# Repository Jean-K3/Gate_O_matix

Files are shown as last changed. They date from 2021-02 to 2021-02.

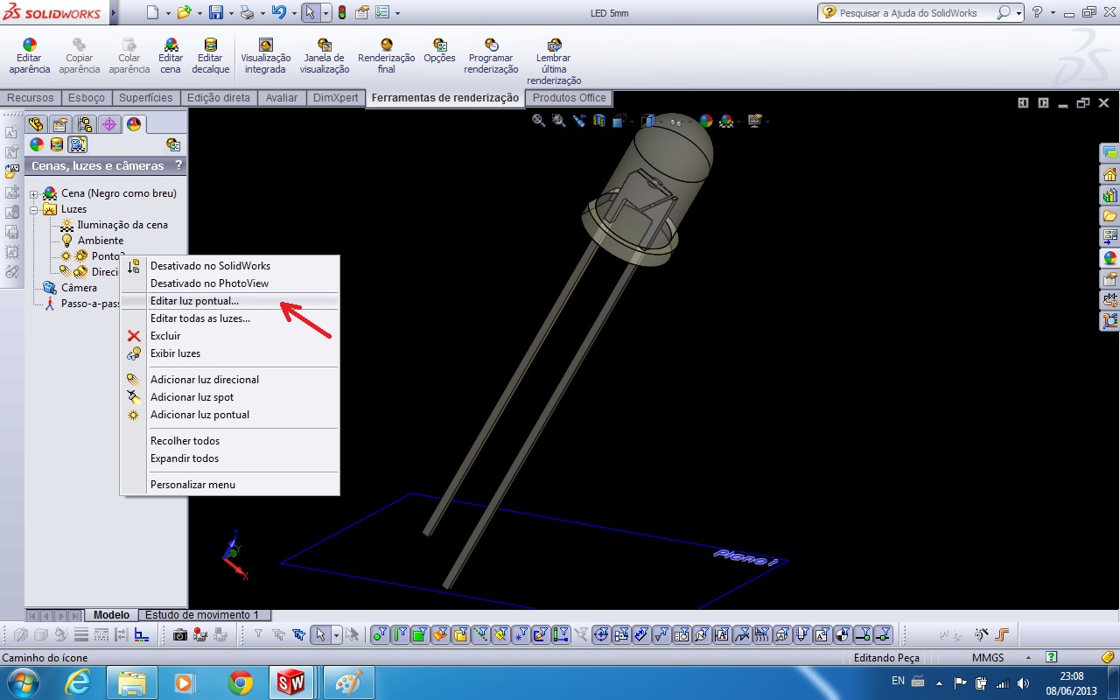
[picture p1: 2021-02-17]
Kicad/My_library/Mes_modèles_3D/LED_5mm/LED 9.jpg

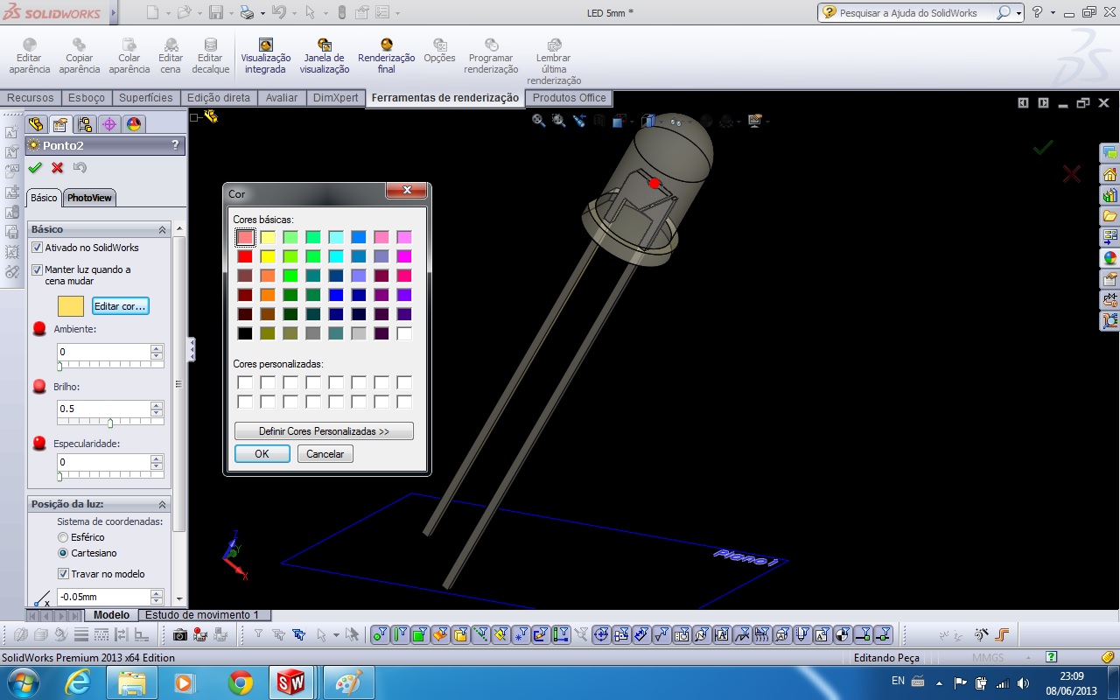
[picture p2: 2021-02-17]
Kicad/My_library/Mes_modèles_3D/LED_5mm/LED 10.jpg

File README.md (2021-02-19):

  Gate sequencer by Plop

  Update 17 FEB 2021

  64 step sequencer, 8 parts, multiple play mode, eurorack format.

  ________________________________________________________________________________________________
  ________________________________________________________________________________________________
  ________________________________________________________________________________________________

  TODO :

    SOFTWARE

      -Clock multiplier/divider per part
      -Detect clock internal/external (switching jack)
      -Reset -> interupt
      -Patern choice
      -Save/Load (SD card)

    HARDWARE

      -Use faster microcontroler (blue pills or teensy ?)
      -Add switching jack for clock
      -Add SD card
      -12v alimentation
      -"transistorisation" des entrées/sorties

    SCHEMATIC & PCB
    
      -Resistor value for LED & screen
      -Routing Main_Board
      -Drawing CPU_Board

  DONE :

    -Tempo
    -Screen driver
    -LED driver
    -Key matrix
    -Part choice
    -Number of step
    -Pages navigation
    -Step ON-OFF
    -Play mode
    -Fill/Clear
    -Copy/Past
    -Pause/Play/Stop
    -Gate size
    -Step jump
    -Reset
    -Internal clock

  ________________________________________________________________________________________________
  ________________________________________________________________________________________________
  ________________________________________________________________________________________________

  FUNCTIONS :

    Buttons =
        -Step on/off
        -Shift + step button = step jump
        -Fill
        -Fill + shift = Clear
        -Copy/Paste
        -Copy/Paste + shift = Save
        -Pause/Play
        -Pause/Play + shift = Stop

    Encoders =
        -Tempo
        -Tempo + push = clock divider
        -Gate length
        -Gate length + push = Number of step
        -Page navigation
        -Page navigation + push = Play mode

    Selector =
        -Part choice

    Play mode =
        -Forward
        -Backward
        -Ping Pong
        -Random
        -Brownien

  --------------------------------------------------------------------------

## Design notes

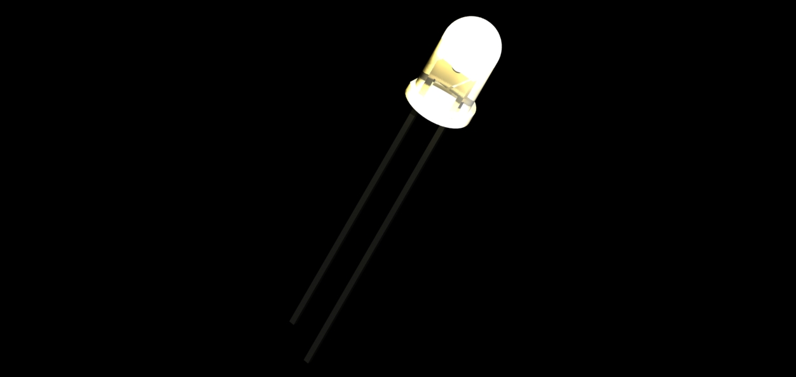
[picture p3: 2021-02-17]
Kicad/My_library/Mes_modèles_3D/LED_5mm/LED 1.JPG

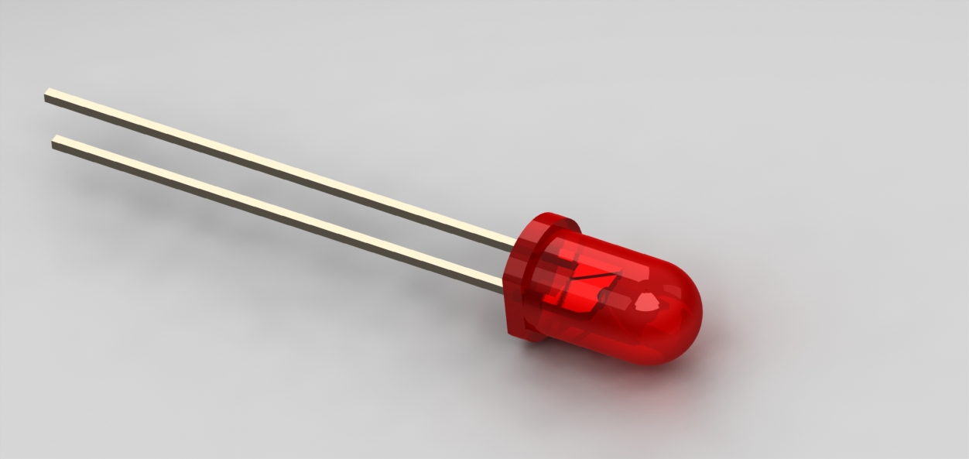
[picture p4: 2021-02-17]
Kicad/My_library/Mes_modèles_3D/LED_5mm/Renderings/LED 13.JPG

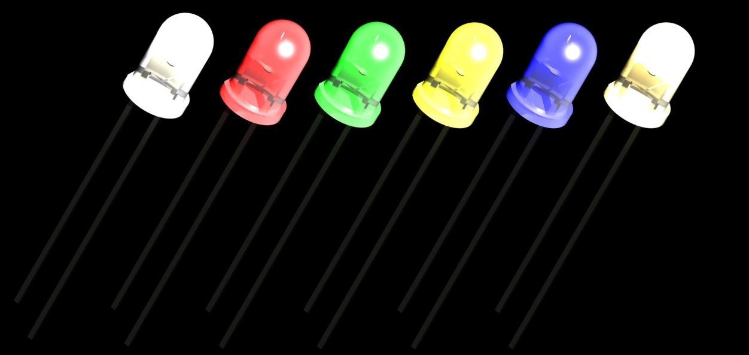
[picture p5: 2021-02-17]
Kicad/My_library/Mes_modèles_3D/LED_5mm/LED 7.jpg

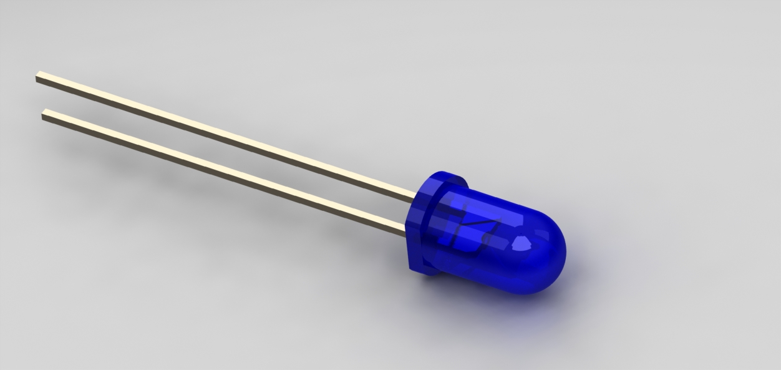
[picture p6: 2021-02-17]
Kicad/My_library/Mes_modèles_3D/LED_5mm/Renderings/LED 17.JPG

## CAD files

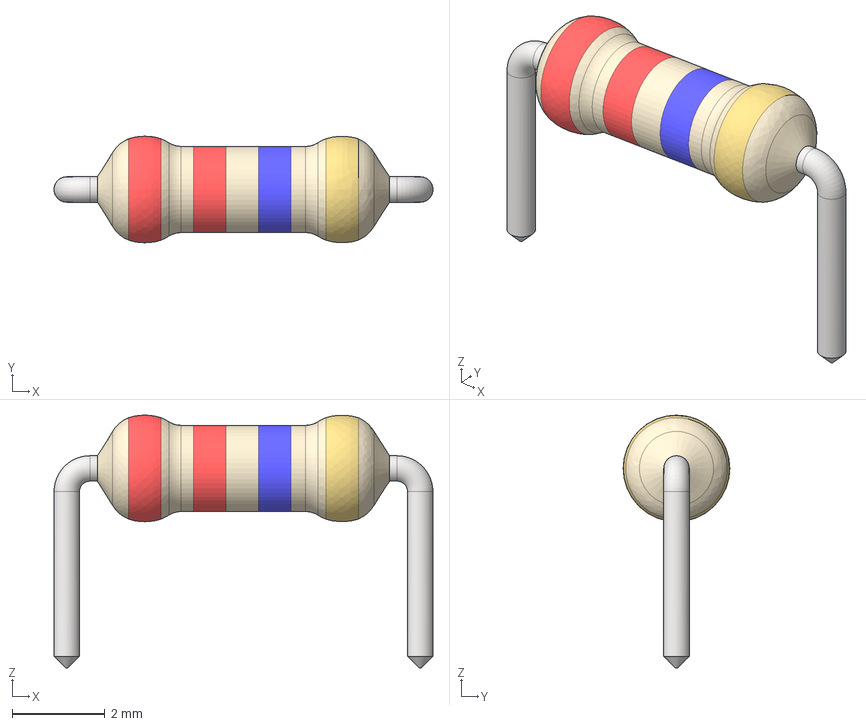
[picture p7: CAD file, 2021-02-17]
Kicad/My_library/Mes_modèles_3D/216-resistors-in-tht-series-e24-from-1ohm-to-910mohm-1.snapshot.3/Yageo CFR-25 Resistor Axial P7.62mm 22,0 MOhm.stp
8.17 x 2.30 x 5.45 mm

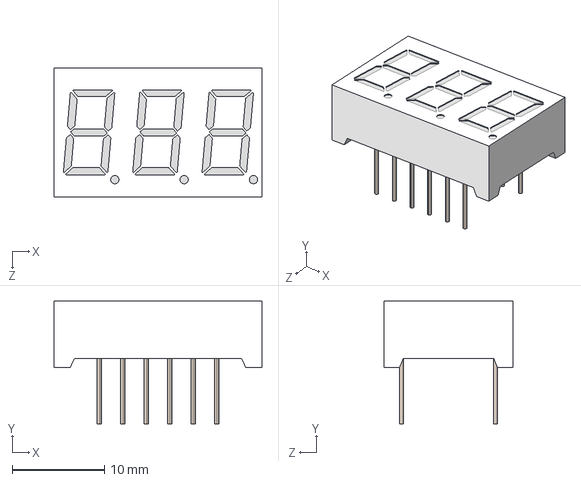
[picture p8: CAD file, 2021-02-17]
Kicad/My_library/Mes_modèles_3D/7 Segment Display/SD-3361_X.STEP
22.5 x 13.3 x 14.0 mm

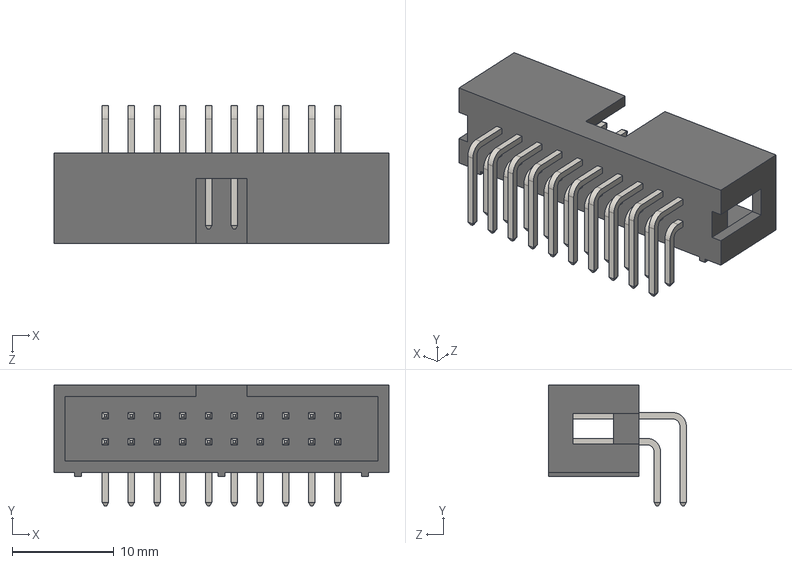
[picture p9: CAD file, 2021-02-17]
Kicad/My_library/Mes_modèles_3D/bh-connector-set-1.snapshot.1/BH-20R.STEP
33.0 x 11.9 x 13.6 mm

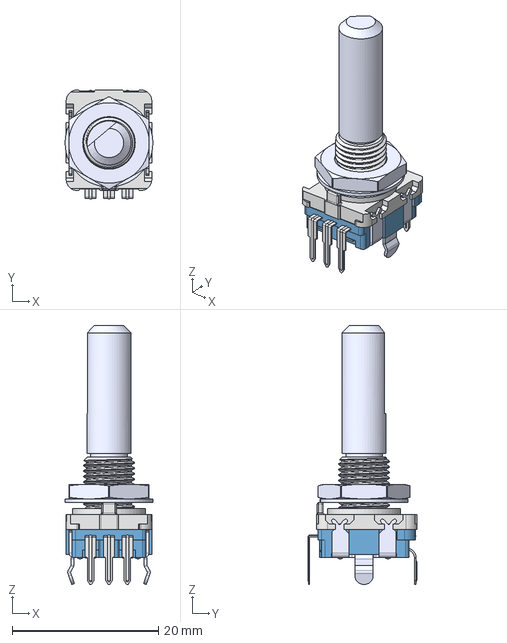
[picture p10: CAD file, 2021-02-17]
Kicad/My_library/Mes_modèles_3D/Encoders/EC11B-SW-Vert-25F-blue.step
12.0 x 14.9 x 35.4 mm

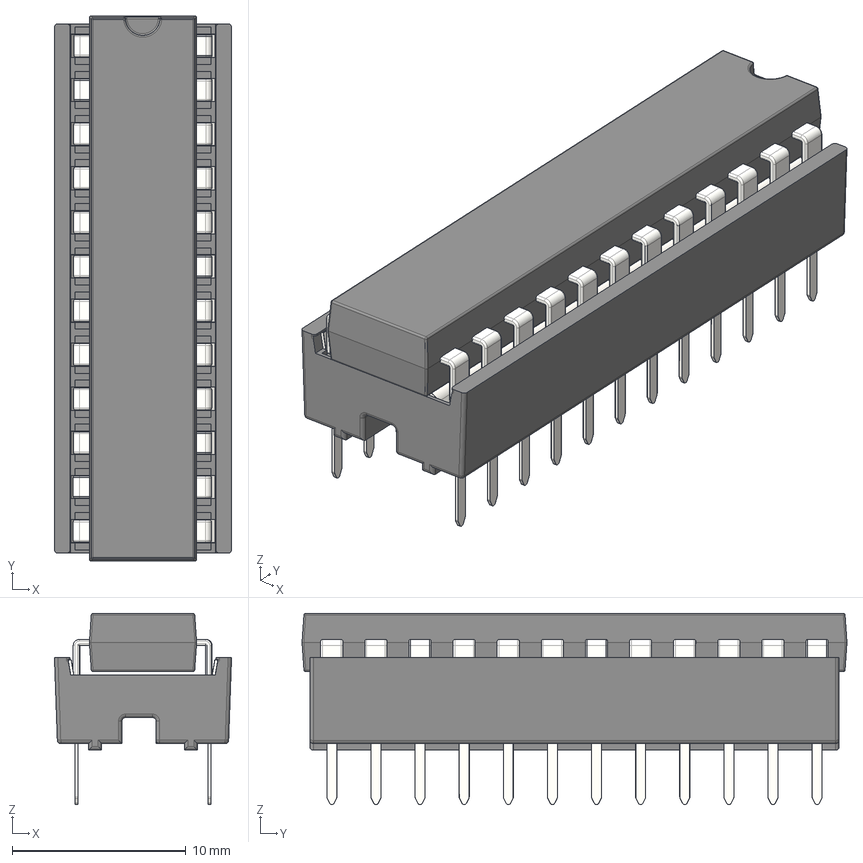
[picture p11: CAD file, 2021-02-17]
Kicad/My_library/Mes_modèles_3D/IC_Sockets/DIP-24 W7.62mm IC with Socket.stp
10.2 x 31.4 x 11.0 mm
Stamped Dual Wipe Contact for DIP Sockets x 24
Body DIP-24 P7.62mm Socket
IC Beinchen x 24
DIP-24 W7.62

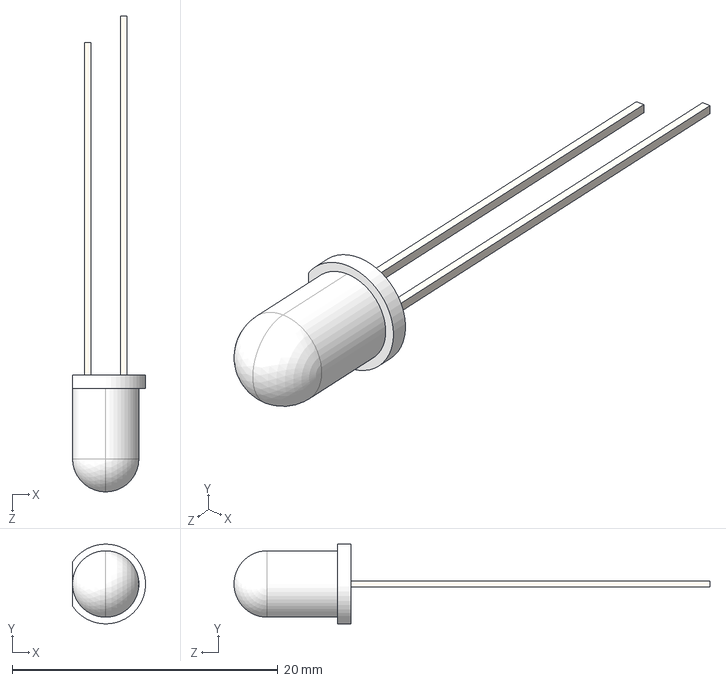
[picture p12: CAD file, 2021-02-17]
Kicad/My_library/Mes_modèles_3D/LED_5mm/LED 5mm.STEP
5.49 x 6.00 x 35.8 mm

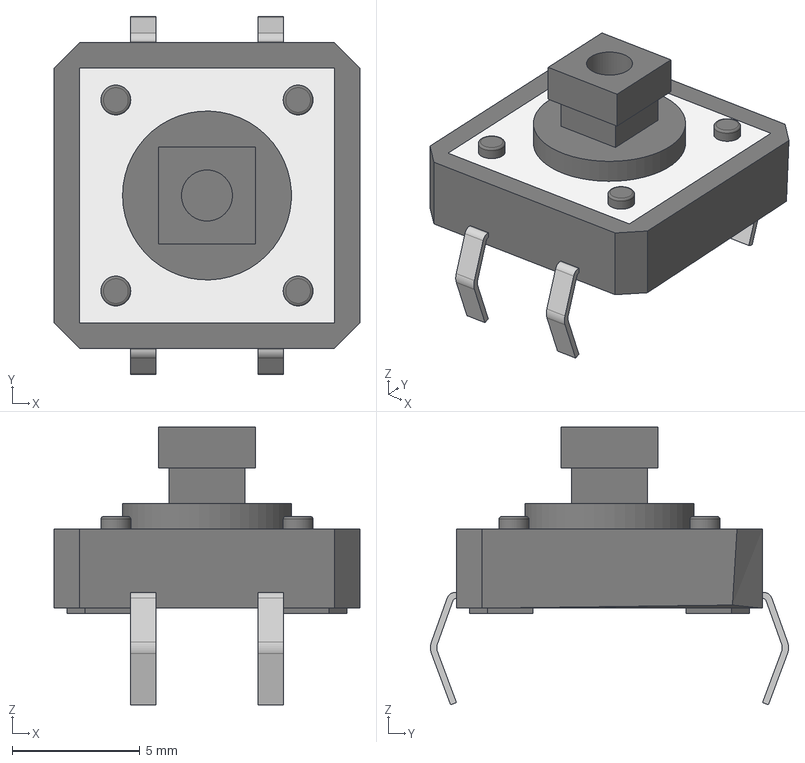
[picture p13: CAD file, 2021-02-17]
Kicad/My_library/Mes_modèles_3D/Switch/TactSwitch.stp
12.0 x 14.0 x 10.9 mm

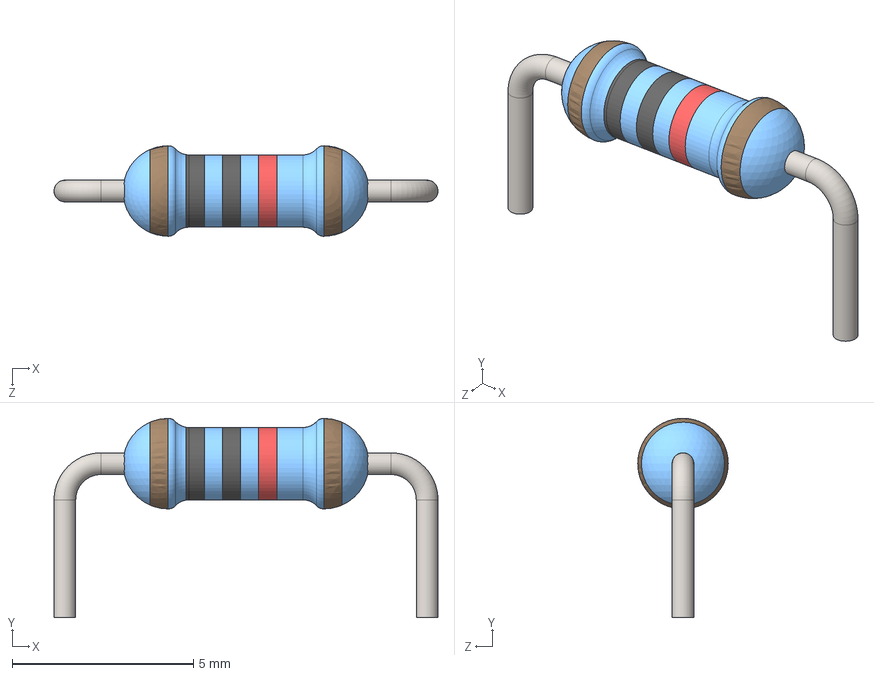
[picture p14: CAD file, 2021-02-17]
Kicad/My_library/Mes_modèles_3D/tht-resistor-1.snapshot.11/10K-1%.STEP
10.6 x 5.50 x 2.50 mm
PinH0.6_10^10K-1%
Body^10K-1%
ColourBand_1^10K-1%
ColourBand_2^10K-1%
ColourBand_3^10K-1%
ColourBand_4^10K-1%
ColourBand_5^10K-1%

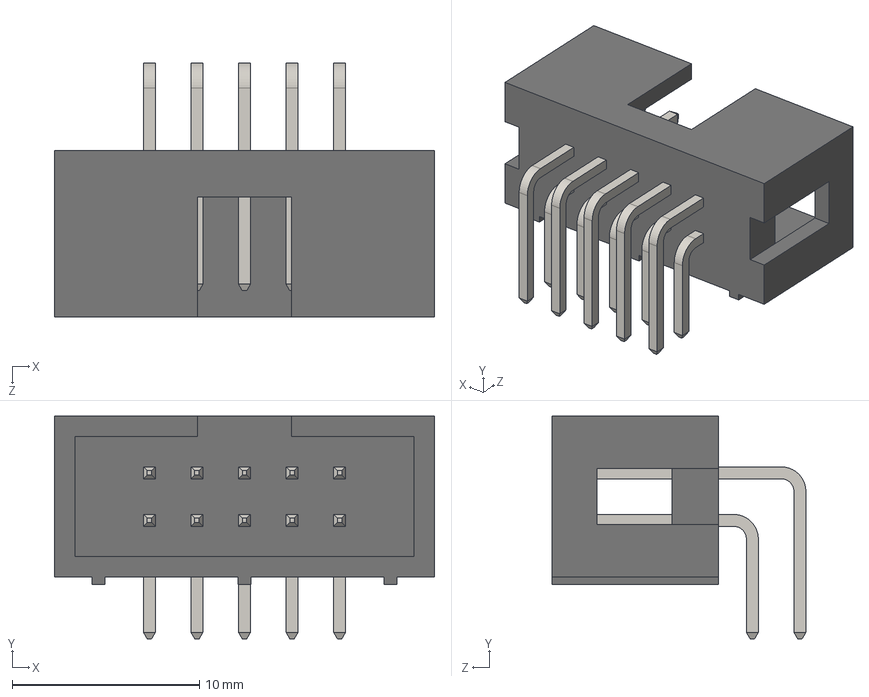
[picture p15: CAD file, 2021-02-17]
Kicad/My_library/Mes_modèles_3D/bh-connector-set-1.snapshot.1/BH-10R.STEP
20.3 x 11.9 x 13.6 mm

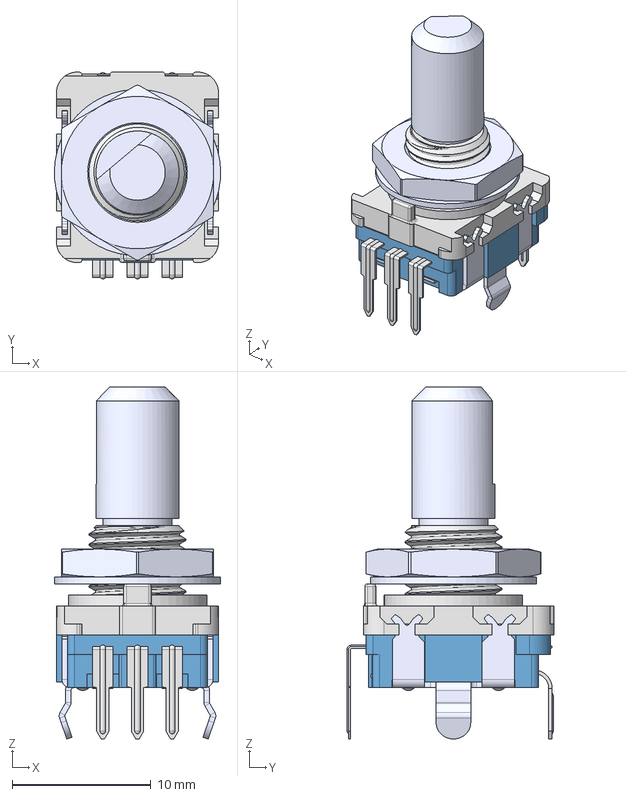
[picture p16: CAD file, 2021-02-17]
Kicad/My_library/Mes_modèles_3D/Encoders/EC11B-SW-Vert-15F-blue.step
12.0 x 14.9 x 25.4 mm

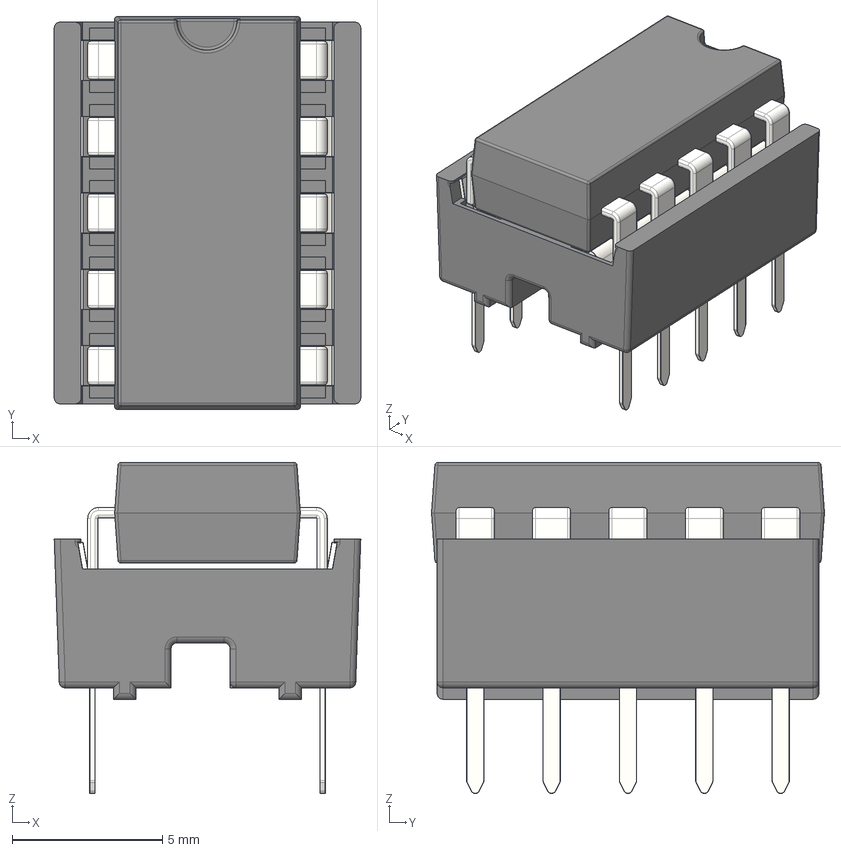
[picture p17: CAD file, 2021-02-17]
Kicad/My_library/Mes_modèles_3D/IC_Sockets/DIP-10 W7.62mm IC with Socket.stp
10.2 x 13.1 x 11.0 mm
Stamped Dual Wipe Contact for DIP Sockets x 10
Body DIP-10 P7.62mm Socket
IC Beinchen x 10
DIP-10 W7.62

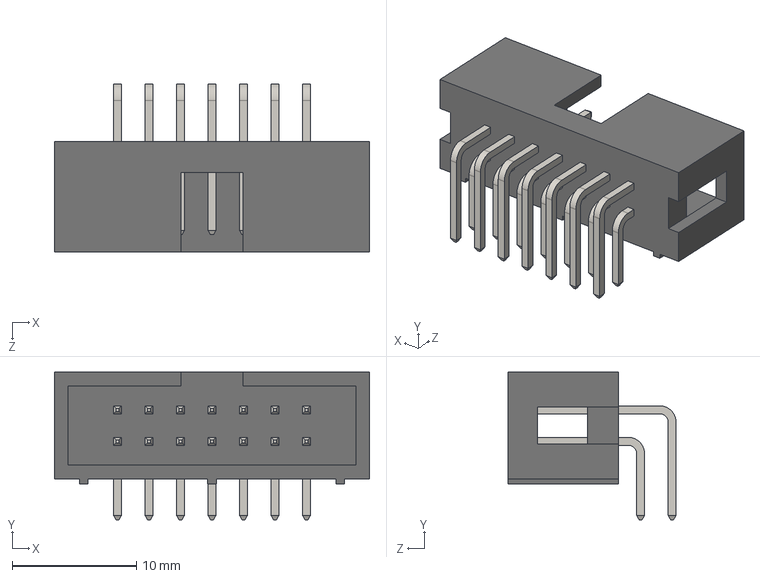
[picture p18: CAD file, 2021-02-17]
Kicad/My_library/Mes_modèles_3D/bh-connector-set-1.snapshot.1/BH-14R.STEP
25.4 x 11.9 x 13.6 mm

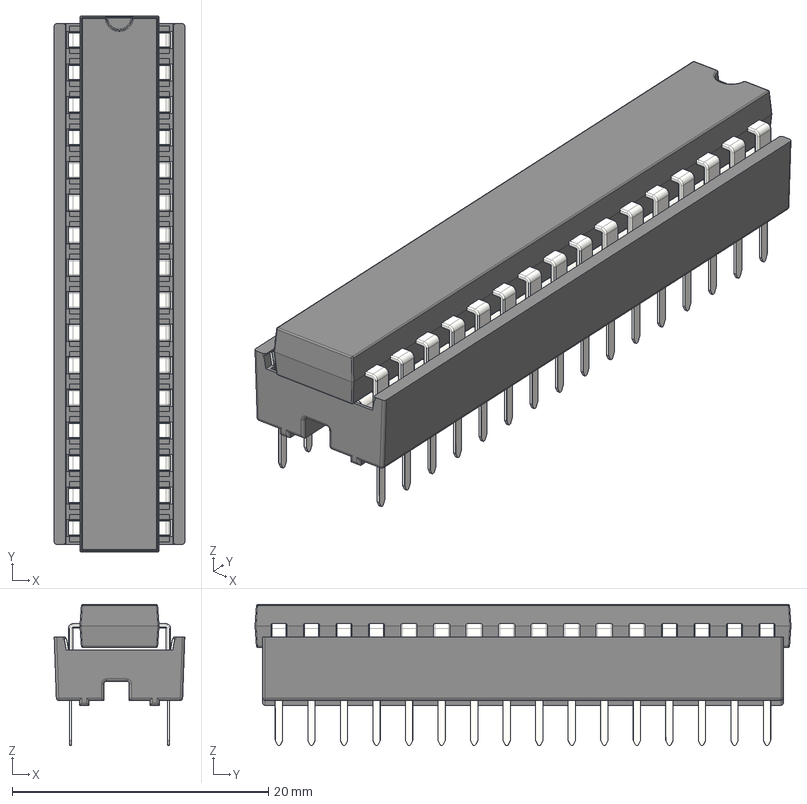
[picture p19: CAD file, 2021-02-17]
Kicad/My_library/Mes_modèles_3D/IC_Sockets/DIP-32 W7.62mm IC with Socket.stp
10.2 x 41.8 x 11.0 mm
Stamped Dual Wipe Contact for DIP Sockets x 32
Body DIP-48 Socket
IC Beinchen x 32
DIP-32 W7.62

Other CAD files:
Kicad/My_library/Mes_modèles_3D/216-resistors-in-tht-series-e24-from-1ohm-to-910mohm-1.snapshot.3/Yageo CFR-25 Resistor Axial P7.62mm 11,0 kOhm.stp
Kicad/My_library/Mes_modèles_3D/tht-resistor-1.snapshot.11/33K-1%.STEP
Kicad/My_library/Mes_modèles_3D/216-resistors-in-tht-series-e24-from-1ohm-to-910mohm-1.snapshot.3/Yageo CFR-25 Resistor Axial P7.62mm 1,3 Ohm.stp
Kicad/My_library/Mes_modèles_3D/Encoders/EC11B-SW-Vert-25R-black.step
Kicad/My_library/Mes_modèles_3D/tht-resistor-1.snapshot.11/560R-1%.STEP
Kicad/My_library/Mes_modèles_3D/216-resistors-in-tht-series-e24-from-1ohm-to-910mohm-1.snapshot.3/Yageo CFR-25 Resistor Axial P7.62mm 1,0 MOhm.stp
Kicad/My_library/Mes_modèles_3D/216-resistors-in-tht-series-e24-from-1ohm-to-910mohm-1.snapshot.3/Yageo CFR-25 Resistor Axial P7.62mm 1,0 Ohm.stp
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

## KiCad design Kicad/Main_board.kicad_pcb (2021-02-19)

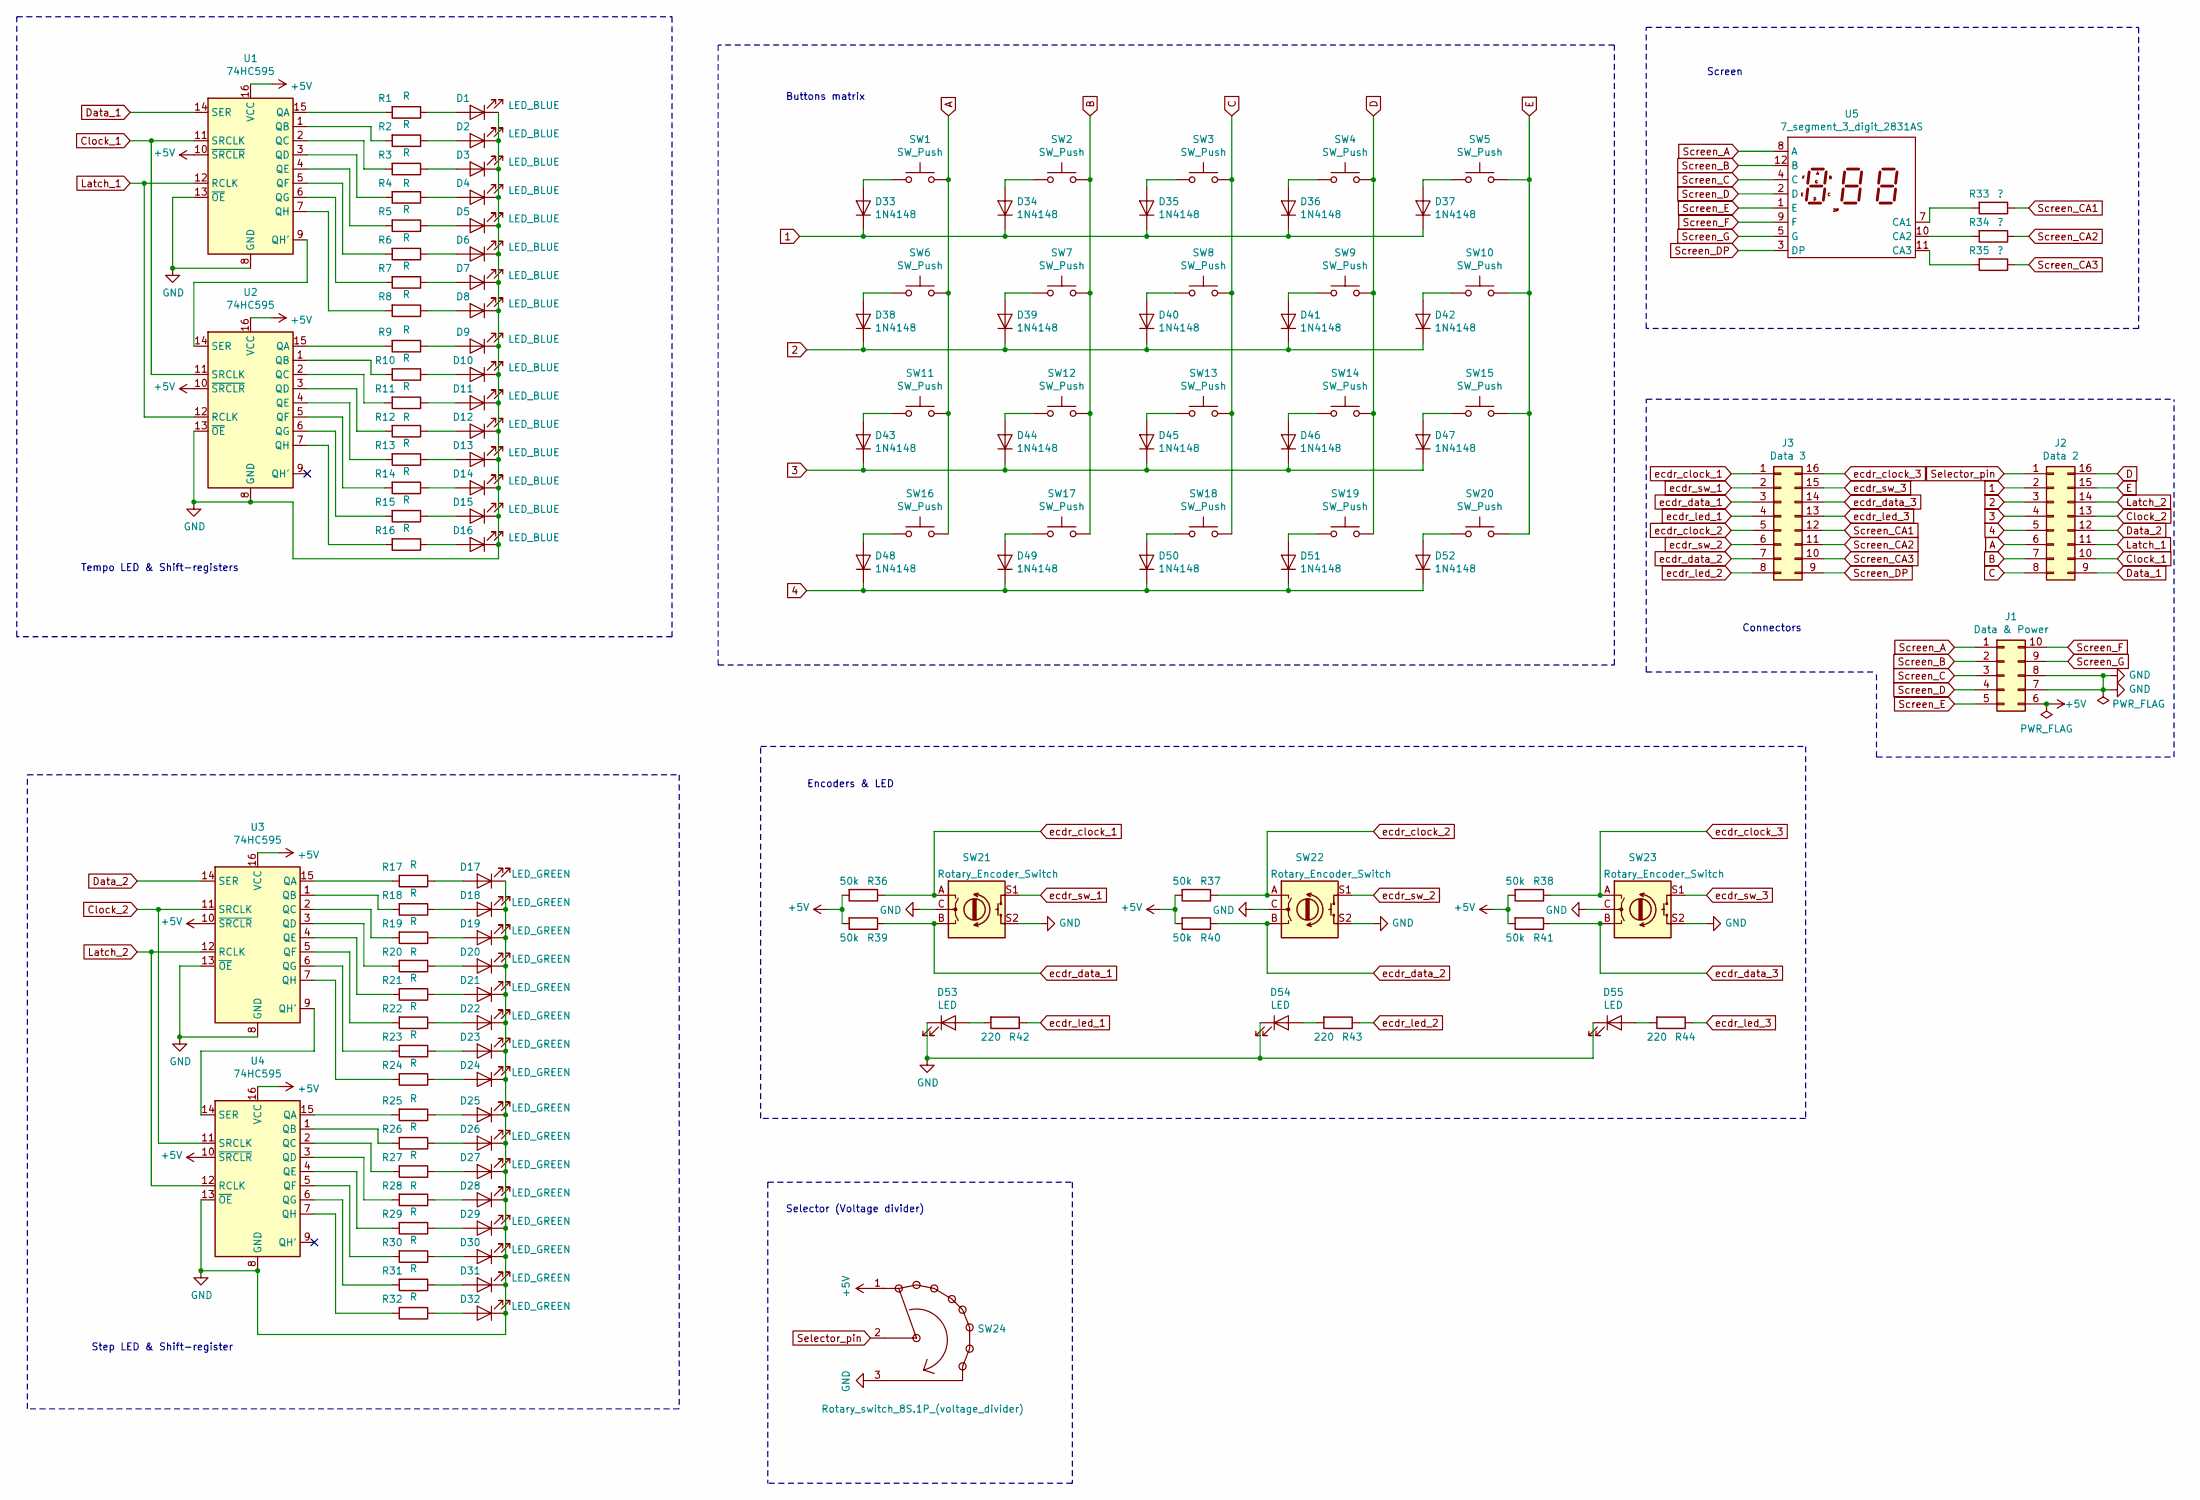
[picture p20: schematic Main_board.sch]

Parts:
D1, D2, D3, D4, D5, D6, D7, D8, D9, D10, D11, D12, D13, D14, D15, D16: LED_BLUE; LED_5.0mm
D17, D18, D19, D20, D21, D22, D23, D24, D25, D26, D27, D28, D29, D30, D31, D32: LED_GREEN; LED_5.0mm
D33, D34, D35, D36, D37, D38, D39, D40, D41, D42, D43, D44, D45, D46, D47, D48, D49, D50, D51, D52: 1N4148; D_DO-35_SOD27_P7.62mm_Horizontal
D53, D54, D55: LED; LED_5.0mm
J1: Data & Power; IDC-Header_2x05
J2: Data 2; IDC-Header_2x08
J3: Data 3; IDC-Header_2x08
R1, R2, R3, R4, R5, R6, R7, R8, R9, R10, R11, R12, R13, R14, R15, R16, R17, R18, R19, R20, R21, R22, R23, R24, R25, R26, R27, R28, R29, R30, R31, R32: R; Resistance
R33, R34, R35: ?; Resistance
R36, R37, R38, R39, R40, R41: 50k; Resistance
R42, R43, R44: 220; Resistance
SW1, SW2, SW3, SW4, SW5, SW6, SW7, SW8, SW9, SW10, SW11, SW12, SW13, SW14, SW15, SW16, SW17, SW18, SW19, SW20: SW_Push; SW_PUSH-12mm(deported)
SW21, SW22, SW23: Rotary_Encoder_Switch; RotaryEncoder
SW24: Rotary_switch_8S.1P_(voltage_divider); SolderWirePad_1x03_Drill1.5mm
U1, U2, U3, U4: 74HC595; DIP-16_Socket
U5: 7_segment_3_digit_2831AS; 7-Segment_2831AS

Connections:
1: D33.1 (K), D34.1 (K), D35.1 (K), D36.1 (K), D37.1 (K), J2.2
2: D38.1 (K), D39.1 (K), D40.1 (K), D41.1 (K), D42.1 (K), J2.3
3: D43.1 (K), D44.1 (K), D45.1 (K), D46.1 (K), D47.1 (K), J2.4
4: D48.1 (K), D49.1 (K), D50.1 (K), D51.1 (K), D52.1 (K), J2.5
+5V: J1.6, R36.2, R37.2, R38.2, R39.2, R40.2, R41.2, SW24.1, U1.10 (~SRCLR), U1.16 (VCC), U2.10 (~SRCLR), U2.16 (VCC), U3.10 (~SRCLR), U3.16 (VCC), U4.10 (~SRCLR), U4.16 (VCC)
A: J2.6, SW1.2, SW6.2, SW11.2, SW16.2
B: J2.7, SW2.2, SW7.2, SW12.2, SW17.2
C: J2.8, SW3.2, SW8.2, SW13.2, SW18.2
Clock_1: J2.10, U1.11 (SRCLK), U2.11 (SRCLK)
Clock_2: J2.13, U3.11 (SRCLK), U4.11 (SRCLK)
D: J2.16, SW4.2, SW9.2, SW14.2, SW19.2
Data_1: J2.9, U1.14 (SER)
Data_2: J2.12, U3.14 (SER)
E: J2.15, SW5.2, SW10.2, SW15.2, SW20.2
GND: D1.1 (K), D2.1 (K), D3.1 (K), D4.1 (K), D5.1 (K), D6.1 (K), D7.1 (K), D8.1 (K), D9.1 (K), D10.1 (K), D11.1 (K), D12.1 (K), D13.1 (K), D14.1 (K), D15.1 (K), D16.1 (K), D17.1 (K), D18.1 (K), D19.1 (K), D20.1 (K), D21.1 (K), D22.1 (K), D23.1 (K), D24.1 (K), D25.1 (K), D26.1 (K), D27.1 (K), D28.1 (K), D29.1 (K), D30.1 (K), D31.1 (K), D32.1 (K), D53.1 (K), D54.1 (K), D55.1 (K), J1.7, J1.8, SW21.C, SW21.S2, SW22.C, SW22.S2, SW23.C, SW23.S2, SW24.3, U1.8 (GND), U1.13 (~OE), U2.8 (GND), U2.13 (~OE), U3.8 (GND), U3.13 (~OE), U4.8 (GND), U4.13 (~OE)
Latch_1: J2.11, U1.12 (RCLK), U2.12 (RCLK)
Latch_2: J2.14, U3.12 (RCLK), U4.12 (RCLK)
unnamed: D1.2 (A), R1.1
unnamed: D2.2 (A), R2.1
unnamed: D3.2 (A), R3.1
unnamed: D4.2 (A), R4.1
unnamed: D5.2 (A), R5.1
unnamed: D6.2 (A), R6.1
unnamed: D7.2 (A), R7.1
unnamed: D8.2 (A), R8.1
unnamed: D9.2 (A), R9.1
unnamed: D10.2 (A), R10.1
unnamed: D11.2 (A), R11.1
unnamed: D12.2 (A), R12.1
unnamed: D13.2 (A), R13.1
unnamed: D14.2 (A), R14.1
unnamed: D15.2 (A), R15.1
unnamed: D16.2 (A), R16.1
unnamed: D17.2 (A), R17.1
unnamed: D18.2 (A), R18.1
unnamed: D19.2 (A), R19.1
unnamed: D20.2 (A), R20.1
unnamed: D21.2 (A), R21.1
unnamed: D22.2 (A), R22.1
unnamed: D23.2 (A), R23.1
unnamed: D24.2 (A), R24.1
unnamed: D25.2 (A), R25.1
unnamed: D26.2 (A), R26.1
unnamed: D27.2 (A), R27.1
unnamed: D28.2 (A), R28.1
unnamed: D29.2 (A), R29.1
unnamed: D30.2 (A), R30.1
unnamed: D31.2 (A), R31.1
unnamed: D32.2 (A), R32.1
unnamed: D33.2 (A), SW1.1
unnamed: D34.2 (A), SW2.1
unnamed: D35.2 (A), SW3.1
unnamed: D36.2 (A), SW4.1
unnamed: D37.2 (A), SW5.1
unnamed: D38.2 (A), SW6.1
unnamed: D39.2 (A), SW7.1
unnamed: D40.2 (A), SW8.1
unnamed: D41.2 (A), SW9.1
unnamed: D42.2 (A), SW10.1
unnamed: D43.2 (A), SW11.1
unnamed: D44.2 (A), SW12.1
unnamed: D45.2 (A), SW13.1
unnamed: D46.2 (A), SW14.1
unnamed: D47.2 (A), SW15.1
unnamed: D48.2 (A), SW16.1
unnamed: D49.2 (A), SW17.1
unnamed: D50.2 (A), SW18.1
unnamed: D51.2 (A), SW19.1
unnamed: D52.2 (A), SW20.1
unnamed: D53.2 (A), R42.2
unnamed: D54.2 (A), R43.2
unnamed: D55.2 (A), R44.2
unnamed: R1.2, U1.15 (QA)
unnamed: R2.2, U1.1 (QB)
unnamed: R3.2, U1.2 (QC)
unnamed: R4.2, U1.3 (QD)
unnamed: R5.2, U1.4 (QE)
unnamed: R6.2, U1.5 (QF)
unnamed: R7.2, U1.6 (QG)
unnamed: R8.2, U1.7 (QH)
unnamed: R9.2, U2.15 (QA)
unnamed: R10.2, U2.1 (QB)
unnamed: R11.2, U2.2 (QC)
unnamed: R12.2, U2.3 (QD)
unnamed: R13.2, U2.4 (QE)
unnamed: R14.2, U2.5 (QF)
unnamed: R15.2, U2.6 (QG)
unnamed: R16.2, U2.7 (QH)
unnamed: R17.2, U3.15 (QA)
unnamed: R18.2, U3.1 (QB)
unnamed: R19.2, U3.2 (QC)
unnamed: R20.2, U3.3 (QD)
unnamed: R21.2, U3.4 (QE)
unnamed: R22.2, U3.5 (QF)
unnamed: R23.2, U3.6 (QG)
unnamed: R24.2, U3.7 (QH)
unnamed: R25.2, U4.15 (QA)
unnamed: R26.2, U4.1 (QB)
unnamed: R27.2, U4.2 (QC)
unnamed: R28.2, U4.3 (QD)
unnamed: R29.2, U4.4 (QE)
unnamed: R30.2, U4.5 (QF)
unnamed: R31.2, U4.6 (QG)
unnamed: R32.2, U4.7 (QH)
unnamed: R33.2, U5.7 (CA1)
unnamed: R34.2, U5.10 (CA2)
unnamed: R35.2, U5.11 (CA3)
unnamed: U1.9 (QH'), U2.14 (SER)
unnamed: U3.9 (QH'), U4.14 (SER)
Screen_A: J1.1, U5.8 (A)
Screen_B: J1.2, U5.12 (B)
Screen_C: J1.3, U5.4 (C)
Screen_CA1: J3.12, R33.1
Screen_CA2: J3.11, R34.1
Screen_CA3: J3.10, R35.1
Screen_D: J1.4, U5.2 (D)
Screen_DP: J3.9, U5.3 (DP)
Screen_E: J1.5, U5.1 (E)
Screen_F: J1.10, U5.9 (F)
Screen_G: J1.9, U5.5 (G)
Selector_pin: J2.1, SW24.2
ecdr_clock_1: J3.1, R36.1, SW21.A
ecdr_clock_2: J3.5, R37.1, SW22.A
ecdr_clock_3: J3.16, R38.1, SW23.A
ecdr_data_1: J3.3, R39.1, SW21.B
ecdr_data_2: J3.7, R40.1, SW22.B
ecdr_data_3: J3.14, R41.1, SW23.B
ecdr_led_1: J3.4, R42.1
ecdr_led_2: J3.8, R43.1
ecdr_led_3: J3.13, R44.1
ecdr_sw_1: J3.2, SW21.S1
ecdr_sw_2: J3.6, SW22.S1
ecdr_sw_3: J3.15, SW23.S1

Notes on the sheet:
Tempo LED & Shift-registers
Step LED & Shift-register
Buttons matrix
Encoders & LED
Selector (Voltage divider)
Screen
Connectors

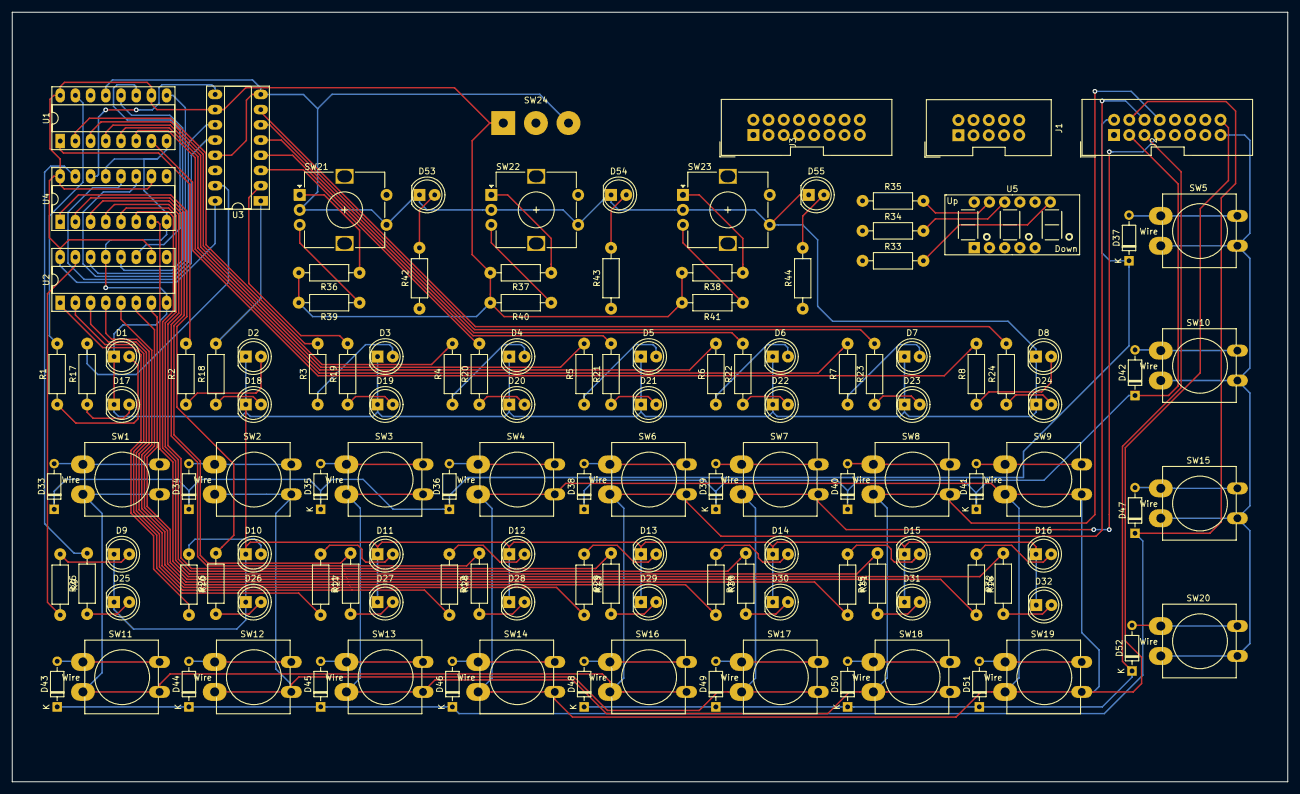
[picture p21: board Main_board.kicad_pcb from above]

Board: 2 copper layers, 213.0 x 128.5 mm, 131 parts (0 on the bottom side), 133 nets.

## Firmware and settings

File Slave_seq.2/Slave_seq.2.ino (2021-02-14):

/*
  =====================================================
  Gate sequencer by Jean_k<3

  Update 08 JAN 2021

  64 step sequencer, 8 part compatible eurorack
  =====================================================

  ________________________________________________________________________________________________
  ________________________________________________________________________________________________
  ________________________________________________________________________________________________

  TODO :

  SOFTWARE

  Clock multiplier/diviser per part
  Detection Clock interne/externe

  Reset -> interupt
  Clock ext -> interupt

  Choix de la paterne (shift + page nav)

  Fonction save/Load (SD card)

  HARDWARE

  Checker si un jack est connecter ou non
  Carte SD
  Alim 12v
  transistorisation des entrées/sorties


  DONE :

  Encodeur Tempo
  Afficheur 7 segments
  Gestion des LEDs
  Matrice de boutons
  Fonction de choix de la part

  Ajout du selecteur
  Fonction de choix de la part
  Fonction de gestion du nombre de pas
  Fonction Pages navigation
  Step ON-OFF
  Fonction sens de lecture
  Fonction Fill/Clear
  Fonction Copy/Past
  Lecture des bouttons de fonctions
  Fonction pause-lecture/stop
  Fonction de gestion de la taille de la gate
  Fonction Step jump
  Reset

  ________________________________________________________________________________________________
  ________________________________________________________________________________________________
  ________________________________________________________________________________________________


  FUNCTION :

  Bouttons
    Shift + step button = step jump
    Fill + shift = Clear
    Copy/Paste + shift = Save
    Pause/Play + shift = Stop

   Encoder
    Tempo + push = clock divider
    Gate length + push = Number of step
    Page navigation + push = Forward/Backward/Random

   Selecter
    Part choice + shift = patern choice

  --------------------------------------------------------------------------

  ANALOGUE PIN
  1 Selecteur pour les parts
  3 encoder pour le tempo/clock divider, gate/step, page/nombre de page

  DIGITAL PIN

  jack : 12
    output
      Clock out
      Reset out
      8 Gate out

     input
        Clock in
        Reset in

  Boutons : 24
    16 bouttons de pas
    5 boutton pour Shift, Copy-Paste, Save/Load, Fill/Clear, Play-Pause/Stop
    3 boutton d'encoder
  (Matrice de boutons 5x5 = 25 boutons disponible)

  Leds : 43
    16 leds de pas
    16 leds timeline
    3 leds de fonctions (une par encoder pour savoir sa fonction actuelle)
    1 led pour le BPM
    Afficheur 3x7 segments 11 pin (7 chathodes+ / 3 anodes-)
  (Matrice de LED en 6*6 = 36 LEDs)
  ( + 7 pour l'afficheur)


*/

#define ALL_STEP 64
#define ALL_PART 8

//---------------------Encoder 1 General/Patern--------------------------

int count;

#define general_SW_pin 2
#define general_inputCLK 3
#define general_inputDT 4
#define general_led_pin A7

bool general_currentStateCLK;
bool general_previousStateCLK;
bool general_SW_state;
bool last_general_SW_state;
bool general = HIGH;

byte which_parameter;
char*  general_param[4] {"PAG", "BPn", "DEL", "SnG"};

byte which_mode;
char* mode[2] {"pat","nut"};

//---------------------Encoder 2 Per Part/Per Step--------------------------
#define per_part_SW_pin A6
#define per_part_inputCLK A4
#define per_part_inputDT A5
#define per_part_led_pin A3

bool per_part_currentStateCLK;
bool per_part_previousStateCLK;
bool per_part_SW_state;
bool last_per_part_SW_state;
bool per_part;
bool per_part_led_state;

byte which_part_param;
char*  part_param[5] {"nbs", "uAY", "ist", "CLO", "gsi"};

byte which_step_param;
char*  step_param[3] {"gsi", "rat", "pby"};

//---------------------Encoder 3 DATA--------------------------
#define data_SW_pin 36
#define data_inputCLK 34
#define data_inputDT 35
#define data_led_pin 37

bool data_currentStateCLK;
bool data_previousStateCLK;
bool data_SW_state;
bool last_data_SW_state;
bool data_led_state;

bool validate;

byte page_pos;
byte BPM;
byte delays;
byte swing;

byte gate_rate[ALL_PART];
byte number_of_step[ALL_PART];
byte which_way;
byte clock_modulator[ALL_PART];
bool inverted_state[ALL_PART];

byte probability[ALL_STEP];
byte racheting[ALL_STEP][4]; // 4 mode de racheting
byte step_gate_rate[ALL_STEP];

bool ping[ALL_PART] = {1};

//---------------------I2C------------------------------
#include <Wire.h>
#include <I2C_Anything.h>
bool changed = false;

//---------------------DISPLAY--------------------------
#include "SevSeg.h"
SevSeg sevseg;
byte to_print[6];
byte which_encoder;
char*  my_string[5] {"frd", "brd", "png", "rnd", "bro"};

//---------------------Selector--------------------------
#define selectorPin A0
const byte gate_out_pin[ALL_PART] = {A8, A9, A10, A11, A12, A13, A14, A15};

const float divider = 146.00;
byte selected_part;
unsigned long previous_time;

//---------------------Le temps--------------------------
bool clock;
bool play;

#define reset_pin 8
bool reset_state;
bool last_reset_state;
unsigned long lastTime;

bool step_to_jump [ALL_STEP];

unsigned long step_start;
float step_length;

int gate_length[ALL_PART];

unsigned long lastDebounceTime = 0;   // For the encoders buttons


//---------------------Buttons Matrix--------------------------
#include <Keypad.h>
#define shift_pin A2
const byte ROWS = 4; //four rows
const byte COLS = 5; //five columns
const byte rowPins[ROWS] = {42, 43, 44, 45}; //connect to the row pinouts of the keypad
const byte colPins[COLS] = {49, 50, 51, 52, 53}; //connect to the column pinouts of the keypad

bool step_state[ALL_PART][ALL_STEP] = {0};
byte which_step[7] = {0}; // To save the last changed step and send it via I2C

bool copied_state[ALL_STEP] = {0};
byte actual_step[ALL_PART];

char keys[ROWS][COLS] = {
  {'a', 'b', 'c', 'd', '1'},
  {'e', 'f', 'g', 'h', '2'},
  {'i', 'j', 'k', 'l', '3'},
  {'m', 'n', 'o', 'p', '4'}
};
Keypad kpd = Keypad( makeKeymap(keys), rowPins, colPins, ROWS, COLS );
byte my_key;

bool shift = false;
bool pause = false;
bool stop = false;
bool copy = false;
bool fill = false;
bool save = false;

//---------------------Step Led--------------------------
const int verrou = 11;    //LATCH PIN
const int horloge = 12;   //CLOCK PIN
const int data = 10;      //DATA  PIN

//---------------------Tempo Led--------------------------
const int verrou2 = 6;    //LATCH PIN
const int horloge2 = 5;   //CLOCK PIN
const int data2 = 7;      //DATA  PIN
unsigned long previous;   // Blink tempo LED if step_jump

//
//============================================================================== HANDLE BUTTONS
//
void Handle_buttons () {

  for (byte i = 0; i < 7; ++i) {
  }

  if (kpd.getKeys()) // Si un boutton bouge
  {
    for (int i = 0; i < LIST_MAX; i++) // on stock son numéro dans une liste
    {
      if (kpd.key[i].stateChanged) { // selon quelle boutton bouge
        my_key = kpd.key[i].kchar;

        switch (kpd.key[i].kstate) {  // Report active key state : IDLE, PRESSED, HOLD, or RELEASED
          case PRESSED:

            if (my_key > 96 && my_key < 113) {

              if (shift == false) {

                changed = true;
                step_state[selected_part][my_key - 97 + page_pos * 16] = !step_state[selected_part][my_key - 97 + page_pos * 16];

                if (i < 6) {
                  which_step[i] = (my_key - 97) + page_pos * 16; // the 6 last step who has changed
                }


              } else if (shift == true) { // jump the step
                step_to_jump[my_key - 97 + page_pos * 16] = !step_to_jump[my_key - 97 + page_pos * 16];
              }
            }
            switch (my_key) {
              case 49 :
                pause = !pause;
                stop = true;
                break;
              case 50 :
                copy = true;
                break;
              case 51 :
                fill = true;
                break;
              case 52 :
                save = true;
                break;
            }
            break;

          case RELEASED :
            switch (my_key) {
              case 49 :
                stop = false;
                break;
              case 50 :
                copy = false;
                break;
              case 51 :
                fill = false;
                break;
              case 52 :
                save = false;
                break;
            }
            break;
        }
      }
    }
  }


  shift = !digitalRead(shift_pin);

  if (!shift) { //_________________ sans le SHIFT

    if (!pause) {
      //Serial.println("play");
      play = true;
    } else if (pause) {
      //Serial.println("paused");
      play = false;
    }

    if (copy)
    {
      //Serial.println("Copied");
      for (int i = 0; i < ALL_STEP; ++i) {
        copied_state[i] = step_state[selected_part][i];              // On copie les états de la voie actuelle
      }
    }

    if (fill) {
      //Serial.println("Filled");
      step_state[selected_part][actual_step[selected_part]] = 1;            // On copie les états de la voie actuelle
    }

    if (save) {
      //Serial.println("Saved");
    }

  } else if (shift) { //_________________ Avec le SHIFT

    if (stop) {
      //Serial.println("stoped");
      play = false;
      pause = true;
      for (int i = 0; i < ALL_PART; ++i) {
        actual_step[i] = 0;
      }
    }

    if (copy)
    {
      //Serial.println("pasted");
      for (int i = 0; i < ALL_STEP; ++i)
      {
        step_state[selected_part][i] = copied_state[i];              // On colle les états de la voie actuelle
      }
    }

    if (fill) {
      //Serial.println("cleared");
      for (int i = 0; i < ALL_STEP; ++ i) {
        step_state[selected_part][i] = 0;
      }
    }

    if (save) {
      //Serial.println("loaded");
    }
  }
}
//
//============================================================================== UPDATE LEDS
//
void update_LEDs() {

  bool tempo_led[ALL_STEP];

  unsigned long current = millis();

  for (int i = 0; i < 16; ++i) {
    if (i + page_pos * 16 == actual_step[selected_part]) {
      tempo_led[i] = true;
    } else {
      tempo_led[i] = false;
    }
  }

  if (current - previous >= 100) {
    previous = current;

    for (int i = 0; i < 16; ++i) {
      if (step_to_jump[i + page_pos * 16]) {
        tempo_led[i] = !tempo_led[i];
      }
    }
  }

  digitalWrite(verrou, LOW);
  digitalWrite(verrou2, LOW);

  for (int i = 16; i >= 0; --i) {
    digitalWrite(horloge, LOW);
    digitalWrite(horloge2, LOW);
    digitalWrite(data, tempo_led[i]);
    digitalWrite(data2, step_state[selected_part][i + page_pos * 16]);
    digitalWrite(horloge, HIGH);
    digitalWrite(horloge2, HIGH);
  }
  digitalWrite(verrou, HIGH);
  digitalWrite(verrou2, HIGH);
}
//
//============================================================================== UPDATE SCREEN
//
void update_screen() {
  
  if (which_encoder == 0) {       // General parameter
    sevseg.setChars(general_param[which_parameter/2]);
  } else if (which_encoder == 1){ // Patern
    sevseg.setChars(mode[which_mode]);
  }else if (which_encoder == 2){  // Per part
    sevseg.setChars(part_param[which_part_param/2]);
  }else if (which_encoder == 3){  // Per step
        sevseg.setChars(step_param[which_step_param/2]);
  }else if (which_encoder == 4){  // Data
    
  }
  sevseg.refreshDisplay();

  //Serial.println(which_encoder);
  // 0 = BPM
  // 1 = Clock Divider
  // 2 = Gate length
  // 3 = number of Step
  // 4 = page navigation
  // 5 = Sens de lecture

  //Serial.println(which_way);
  // 0 = Frd forward
  // 1 = Brd Backward
  // 2 = Png Ping Pong
  // 3 = rnd Random
  // 4 = Bro
}
//
//============================================================================== RESET
//
void reset() {

  int reading = digitalRead(reset_pin);
  if (reading != last_reset_state) {
    lastTime = millis();
  }

  if ((millis() - lastTime) > 5) {

    if (reading != reset_state) {
      reset_state = reading;


      if (reset_state == HIGH) {
        for (int i = 0; i < ALL_PART; ++i) {
          actual_step[i] = 0;
        }
      }
    }
  }
  last_reset_state = reading;
}
//
//============================================================================== NEXT STEP
//
void next_step() {

  switch (which_way) {

    case 0 : // forward

      for (int i = 0; i < ALL_PART; ++i) {

        ++actual_step[i];

        while (step_to_jump[actual_step[i]]) {
          ++actual_step[i];
        }


        if (actual_step[i] > number_of_step[i] - 1) {
          actual_step[i] = 0;
          while (step_to_jump[actual_step[i]]) {
            ++actual_step[i];
          }
        }
      }
      break;

    case 1 : // backward
      for (int i = 0; i < ALL_PART; ++i) {
        --actual_step[i];

        while (step_to_jump[actual_step[i]]) {
          --actual_step[i];
        }


        if (actual_step[i] > 65) {
          actual_step[i] = number_of_step[i] - 1;
          while (step_to_jump[actual_step[i]]) {
            --actual_step[i];
          }
        }
      }
      break;

    case 2 : // ping pong

      byte last_valid_step[ALL_PART];

      for (int i = 0; i < ALL_PART; ++i) {

        if (ping[i]) {
          ++actual_step[i];
          last_valid_step[i] = actual_step[i];

          while (step_to_jump[actual_step[i]]) {
            ++actual_step[i];
            if (actual_step[i] > number_of_step[i] - 1) {
              actual_step[i] = last_valid_step[i] - 2;
              ping[i] = false;
            }
          }

          if (actual_step[i] >= number_of_step[i] - 1) {
            ping[i] = false;
          }

        } else {
          --actual_step[i];
          last_valid_step[i] = actual_step[i];

          while (step_to_jump[actual_step[i]]) {
            --actual_step[i];
            if (actual_step[i] > 65) {
              actual_step[i] = last_valid_step[i] + 2;
              ping[i] = true;
            }
          }

          if (actual_step[i] > 65) {
            ping[i] = true;
          }
        }
      }
      break;

    case 3 :  // random

      for (int i = 0; i < ALL_PART; ++i) {

        byte my_try = random(number_of_step[i]);

        while (step_to_jump[my_try]) {
          my_try = random(number_of_step[i]);
        }
        actual_step[i] = my_try;
      }
      break;

    case 4 : // brownien

      for (int i = 0; i < ALL_PART; ++i) {

        byte proba = random(100);
        byte my_try = random(100);

        if (proba > my_try) {
          ++actual_step[i];

          while (step_to_jump[actual_step[i]]) {
            ++actual_step[i];
          }


          if (actual_step[i] > number_of_step[i] - 1) {
            actual_step[i] = 0;
            while (step_to_jump[actual_step[i]]) {
              ++actual_step[i];
            }
          }
        }
      }
      break;
  }
  step_start = millis();
}
//
//============================================================================== SETUP
//

void clock_ISR() {
  clock = HIGH;
}

void setup() {

  Serial.begin(115200);

  Wire.begin(1);                // join i2c bus with address #8
  Wire.onRequest(requestEvent); // register event

  attachInterrupt(digitalPinToInterrupt(19), clock_ISR, RISING);

  byte numDigits = 3;
  byte digitPins[] = {22, 23, 24}; // 1 2 3
  byte segmentPins[] = {25, 26, 27, 28, 29, 30, 31}; // A B C D E F G
  byte hardwareConfig = COMMON_CATHODE; // See README.md for options
  bool disableDecPoint = true; // Use 'true' if your decimal point doesn't exist or isn't connected

  sevseg.begin(hardwareConfig, numDigits, digitPins, segmentPins, disableDecPoint);
  sevseg.setBrightness(100);

  pinMode(verrou, OUTPUT);
  pinMode(horloge, OUTPUT);
  pinMode(data, OUTPUT);

  pinMode(verrou2, OUTPUT);
  pinMode(horloge2, OUTPUT);
  pinMode(data2, OUTPUT);

  pinMode(general_SW_pin, INPUT_PULLUP);
  pinMode(general_led_pin, OUTPUT);
  pinMode (general_inputCLK, INPUT);
  pinMode (general_inputDT, INPUT);

  pinMode(per_part_SW_pin, INPUT_PULLUP);
  pinMode(per_part_led_pin, OUTPUT);
  pinMode (per_part_inputCLK, INPUT);
  pinMode (per_part_inputDT, INPUT);

  pinMode(data_SW_pin, INPUT_PULLUP);
  pinMode(data_led_pin, OUTPUT);
  pinMode (data_inputCLK, INPUT);
  pinMode (data_inputDT, INPUT);

  general_previousStateCLK = digitalRead(general_inputCLK);
  per_part_previousStateCLK = digitalRead(per_part_inputCLK);
  data_previousStateCLK = digitalRead(data_inputCLK);

  for (int i = 0; i < ALL_PART; ++i) {
    pinMode(gate_out_pin[i], OUTPUT);
  }

  pinMode(shift_pin, INPUT_PULLUP);
  pinMode(reset_pin, INPUT);

  pause = true;                     // Sur pause par défaut
}
//
//==============================================================================
//
void loop() {

  unsigned long current_time = millis();
  if (current_time - previous_time >= 100UL) { // check for the selector every 100ms
    previous_time = current_time;
    selected_part = round(analogRead(selectorPin) / divider);
  }

  Handle_buttons();
  Handle_encoder();
  update_screen();
  update_LEDs();

  reset();

  if (play) {
    if (clock == HIGH) {
      next_step();
      clock = LOW;
    }
  }
}

void requestEvent() {

  Wire.write(gate_rate, 8);         // 8 bytes
  Wire.write(actual_step, 8);       // 8 bytes
  Wire.write(which_step, 6);        // 6 bytes (the last modified step)
  Wire.write(selected_part);        // 1 byte
  Wire.write(changed);              // 1 byte
  Wire.write(BPM);                  // 1 byte
  //  Wire.write(clockDivider);         // 1 byte

  //                           Total : 26 bytes

  changed = false;
  for (byte i = 0; i < 6; ++i) {
    which_step[i] = 88;
  }

}

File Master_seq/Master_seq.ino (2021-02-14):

#include <Wire.h>
#include <I2C_Anything.h>

#define ALL_PART 8
#define ALL_STEP 64
#define DEBUG false

const byte gate_out_pin[ALL_PART] = {4, 5, 6, 7, 8, 9, 10, 11};

int gate_length[ALL_PART];
bool in_time[ALL_PART];

unsigned long step_start = 0;

bool step_state[ALL_PART][ALL_STEP] = {0};
bool copied_state[ALL_STEP] = {0};

// from the slave
byte gate_rate[ALL_PART] = {0};                 // 8 bytes
byte actual_step[ALL_PART] = {0} ;              // 8 bytes
byte which_step[7] = {0};                       // 6 byte
byte selected_part = 0;                         // 1 byte
bool changed = false;                           // 1 byte
int BPM = 120;                                  // 4 byte
byte which_clock = 17;                          // 1 byte

bool shift;                                     // 1 byte
bool copy;                                      // 1 byte
bool fill;                                      // 1 byte
bool save;                                      // 1 byte
//                                        Total = 32 bytes
float step_length = 0;
float clock_modulator[35] = {0.0625, 0.0666, 0.0714, 0.0769, 0.0833, 0.0909, 0.1, 0.1111, 0.125, 0.1428, 0.1666, 0.2, 0.25, 0.3333, 0.4, 0.5, 0.6666, 1, 1.5, 2, 2.5, 3, 4, 5, 6, 7, 8, 9, 10, 11, 12, 13, 14, 15, 16};
//
//============================================================================== FUNCTIONS
//
void handle_function() {
  if (!shift) { //_________________ sans le SHIFT

    if (copy)
    {
      //Serial.println("Copied");
      for (int i = 0; i < ALL_STEP; ++i) {
        copied_state[i] = step_state[selected_part][i];              // On copie les états de la voie actuelle
      }
    }

    if (fill) {
      //Serial.println("Filled");
      step_state[selected_part][actual_step[selected_part]] = 1;     // On remplie tous les pas de la voie
    }

    if (save) {
      //Serial.println("Saved");
    }

  } else if (shift) { //_________________ Avec le SHIFT

    if (copy)
    {
      //Serial.println("pasted");
      for (int i = 0; i < ALL_STEP; ++i)
      {
        step_state[selected_part][i] = copied_state[i];              // On colle les états de la voie actuelle
      }
    }

    if (fill) {
      //Serial.println("cleared");
      for (int i = 0; i < ALL_STEP; ++ i) {
        step_state[selected_part][i] = 0;
      }
    }

    if (save) {
      //Serial.println("loaded");
    }
  }
}
//
//============================================================================== CLOCK
//
void the_clock() {

  const float X = 60000.0;
  float Y = BPM; // convert BPM in a float

  step_length = (X / Y) * clock_modulator[which_clock];

  if (millis() - step_start >= step_length)  // Si on dépasse la taille du STEP
  {
    step_start = millis();
    digitalWrite(3, HIGH);
    for (byte i = 0; i < ALL_PART; ++i) {
      in_time[i] = true;
    }
  }
  digitalWrite(3, LOW);
}
//
//============================================================================== SETUP
//
void setup() {

  Wire.begin();        // join i2c bus (address optional for master)
  Serial.begin(115200);  // start serial for output

  pinMode(3, OUTPUT);

  for (byte i = 0; i < ALL_PART; ++i) {
    pinMode(gate_out_pin[i], OUTPUT);
  }
}
//
//============================================================================== LOOP
//
void loop() {

  request_data();                       // Get the data from the slave

  if (changed) {                        // If a step_state has changed, update it (slave send which_step) or send 88 if any
    for (byte i = 0; i < 6; ++i) {      // Slave send 6 or less address to update

      if (which_step[i] <= 64) {        // If it's 88 = nothing changed
        step_state[selected_part][which_step[i]] = !step_state[selected_part][which_step[i]];
      }
    }
  }


  for (int i = 0; i < ALL_PART; ++i) {

    gate_length[i] = gate_rate[i] * (step_length / 100);

    if (step_state[i][actual_step[i]]) {

      if (millis() - step_start >= gate_length[i]) {
        in_time[i] = false;
      }
      if (in_time[i]) {
        digitalWrite(gate_out_pin[i], HIGH);  // INVERTED because of NPN transistor
      }
    }

    if (!step_state[i][actual_step[i]] || !in_time[i]) {
      digitalWrite(gate_out_pin[i], LOW);  // INVERTED because of NPN transistor
    }
  }

  the_clock();

  if (DEBUG) {
    print_debug();
  }

}
//
//============================================================================== REQUEST_DATA
//
void request_data() {

  Wire.requestFrom(1, 30);            // request 32 bytes from slave device #1

  while (Wire.available()) {

    for (byte i = 0; i < 8; ++i) {    // 8 bytes
      gate_rate[i] = Wire.read();
    }
    for (byte i = 0; i < 8; ++i) {    // 8 bytes
      actual_step[i] = Wire.read();
    }

    for (byte i = 0; i < 6; ++i) {    // 6 bytes
      which_step[i] = Wire.read();
    }

    selected_part = Wire.read();      // 1 byte
    changed = Wire.read();            // 1 byte
    I2C_readAnything (BPM);           // 2 byte
    which_clock = Wire.read();        // 1 byte
    shift = Wire.read();              // 1 byte
    copy = Wire.read();               // 1 byte
    fill = Wire.read();               // 1 byte
  }
}
//
//============================================================================== PRINT_DEBUG
//
void print_debug() {

  Serial.println("=========================");
  Serial.print(" BPM : ");
  Serial.println(BPM);
  Serial.print("step start : ");
  Serial.println(step_start);
  Serial.print("step length : ");
  Serial.println(step_length);
  Serial.print("clock modulator : ");
  Serial.println(clock_modulator[which_clock]);
  Serial.print("which clock : ");
  Serial.println(which_clock);

  Serial.println("___________________________________________________________________________________________________");

  Serial.println(" n°| actual step | gate rate | Page 1          | Page 2         | Page 3         | Page 4         |");
  for (byte i = 0; i < ALL_PART; ++i) {
    Serial.print(" ");
    Serial.print(i + 1);
    Serial.print(" | ");
    Serial.print(actual_step[i]);
    if (actual_step[i] < 10) {
      Serial.print("           | ");
    } else {
      Serial.print("          | ");
    }
    Serial.print(gate_rate[i]);
    Serial.print("       | ");
    for (byte j = 0; j < ALL_STEP; ++j) {
      Serial.print(step_state[i][j]);
      if (j == 15 | j == 31 | j == 47 | j == 63) {
        Serial.print ("|");
      }
    }
    Serial.println();
  }
  Serial.println("__________________________________________________________________________________________________|");

  Serial.print("Selected part : ");
  Serial.print(selected_part);

  for (byte i = 0; i < 10; ++i) {
    Serial.println();
  }
}

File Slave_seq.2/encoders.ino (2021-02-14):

void Handle_encoder() {

  //_____________________________________________________
  int reading_general = digitalRead(general_SW_pin);

  if (reading_general != last_general_SW_state) {
    lastDebounceTime = millis();
  }
  Serial.print(millis());
  Serial.print(" - ");
  Serial.println(lastDebounceTime);
  Serial.println(millis() - lastDebounceTime);

  if ((millis() - lastDebounceTime) > 50UL) {

    if (reading_general != general_SW_state) {
      general_SW_state = reading_general;

      if (general_SW_state == HIGH) {
        general = !general;
      }
      if (general) {
        which_encoder = 0; //General parameter
      } else {
        which_encoder = 1; //Patern mode
      }
    }
  }
  last_general_SW_state = reading_general;

  //_____________________________________________________
  int reading_per_part = digitalRead(per_part_SW_pin);

  if (reading_per_part != last_per_part_SW_state) {
    lastDebounceTime = millis();
  }
  if ((millis() - lastDebounceTime) > 50UL) {

    if (reading_per_part != per_part_SW_state) {
      per_part_SW_state = reading_per_part;

      if (per_part_SW_state == HIGH) {
        per_part = !per_part;
      }
      if (per_part) {
        which_encoder = 2;  // per part parameter
      } else {
        which_encoder = 3;  // per step parameter
      }
    }
  }
  last_per_part_SW_state = reading_per_part;
  //_____________________________________________________
  int reading_data = digitalRead(data_SW_pin);

  if (reading_data != last_data_SW_state) {
    lastDebounceTime = millis();
  }
  if ((millis() - lastDebounceTime) > 50UL) {

    if (reading_data != data_SW_state) {
      data_SW_state = reading_data;

      if (data_SW_state == HIGH) {
        validate = true;
      } else {
        validate = false;
      }
    }
  }
  last_data_SW_state = reading_data;
  //=========================================================================================
  //
  //                                      GENERAL
  //
  //=========================================================================================
  if (general) {                   // Mode = general parameter
    digitalWrite(general_led_pin, LOW);
    general_currentStateCLK = digitalRead(general_inputCLK);

    if (general_currentStateCLK != general_previousStateCLK) {
      which_encoder = 0;
      if (digitalRead(general_inputDT) != general_currentStateCLK) {
        which_parameter--;
      } else {
        which_parameter++;
      }
    }
    general_previousStateCLK = general_currentStateCLK;

    if (which_parameter > 250) {
      which_parameter = 0;
    }
    if (which_parameter > 6) {
      which_parameter = 6;
    }
    //=========================================================================================
    //
    //                                            PATERN
    //
    //=========================================================================================
  } else {                           // Mode = patern
    digitalWrite (general_led_pin, HIGH);
    general_currentStateCLK = digitalRead(general_inputCLK);

    if (general_currentStateCLK != general_previousStateCLK) {
      which_encoder = 1;
      if (digitalRead(general_inputDT) != general_currentStateCLK) {
        which_mode = 0;
      } else {
        which_mode = 1;
      }
    }
    general_previousStateCLK = general_currentStateCLK;
  }
  //=========================================================================================
  //
  //                                      PER PART
  //
  //=========================================================================================
  if (per_part) {                   // Mode = per_part
    digitalWrite(per_part_led_pin, LOW);
    per_part_currentStateCLK = digitalRead(per_part_inputCLK);

    if (per_part_currentStateCLK != per_part_previousStateCLK) {
      which_encoder = 2;
      if (digitalRead(per_part_inputDT) != per_part_currentStateCLK) {
        which_part_param--;
      } else {
        which_part_param++;
      }
    }
    per_part_previousStateCLK = per_part_currentStateCLK;

    if (which_part_param > 250) {
      which_part_param = 0;
    }
    if (which_part_param > 8) {
      which_part_param = 8;
    }
    //=========================================================================================
    //
    //                                      PER STEP
    //
    //=========================================================================================

  } else {                           // Mode per_step
    digitalWrite (per_part_led_pin, HIGH);
    per_part_currentStateCLK = digitalRead(per_part_inputCLK);

    if (per_part_currentStateCLK != per_part_previousStateCLK) {
      which_encoder = 3;
      if (digitalRead(per_part_inputDT) != per_part_currentStateCLK) {
        which_step_param--;
      } else {
        which_step_param++;
      }
    }
    per_part_previousStateCLK = per_part_currentStateCLK;

    if (which_step_param > 250) {
      which_step_param = 0;
    }
    if (which_step_param > 4) {
      which_step_param = 4;
    }
  }

  //=========================================================================================
  //
  //                                      DATA
  //
  //=========================================================================================
  data_currentStateCLK = digitalRead(data_inputCLK);

  if (data_currentStateCLK != data_previousStateCLK) {
    which_encoder = 4;
    if (digitalRead(data_inputDT) != data_currentStateCLK) {
      count --;
    } else {
      count ++;
    }
  }
  data_previousStateCLK = data_currentStateCLK;

}

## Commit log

2021-02-14 supprimé : Gate_O_Matix_v_0.1/Gate_O_Matix_v_0.1.ino supprimé : Gate_O_Matix_v_0.2.ino nouveau fichier : Master_seq/Master_seq.ino modifié : README.md nouveau fichier : Slave_seq.2/Slave_seq.2.ino no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
2021-02-14 nouveau fichier : Gate_omatik.sch
    [Gate_omatik.sch]
2021-02-16 supprimé : Gate_omatik.sch nouveau fichier : Kicad/CPU_board.pro nouveau fichier : Kicad/CPU_board.sch nouveau fichier : Kicad/Main_board.pro nouveau fichier : Kicad/Main_board.sch nouveau fichier : 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
    [CPU_board.sch, Gate_omatik.sch, Main_board.sch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]
2021-02-16 supprimé : Kicad/CPU_board-cache.lib modifié : Kicad/CPU_board.pro modifié : Kicad/CPU_board.sch supprimé : Kicad/CPU_board.sch-bak supprimé : Kicad/Main_board-cache.lib modifié : Kicad/Main_board.sc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
    [CPU_board.sch, Main_board.sch, Screen_board.sch]
2021-02-16 nouveau fichier : My_library/00_Mes_empreintes.pretty/2X05_Power_conn.kicad_mod nouveau fichier : My_library/00_Mes_empreintes.pretty/2n3904.kicad_mod nouveau fichier : My_library/00_Mes_empreintes.p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
2021-02-16 nouveau fichier : Kicad/Main_board-cache.lib nouveau fichier : Kicad/Main_board.kicad_pcb nouveau fichier : Kicad/Main_board.kicad_pcb-bak nouveau fichier : Kicad/Main_board.net modifié : Kicad/Main_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
    [Main_board.kicad_pcb]
2021-02-16 supprimé : Main_board-cache.lib supprimé : Main_board.kicad_pcb-bak supprimé : Main_board.sch-bak supprimé : fp-info-cache supprimé : sym-lib-table
2021-02-16 modifié : CPU_board.sch modifié : Main_board.kicad_pcb modifié : Main_board.sch
2021-02-17 modifié : Kicad/Main_board-cache.lib modifié : Kicad/Main_board.kicad_pcb modifié : Kicad/Main_board.net modifié : Kicad/Main_board.sch nouveau fichier : Kicad/My_library/00_Mes_empreintes.pretty/7-S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
    [10K-1%.STEP, 180R-1%.STEP, 1K2-1%.STEP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]
2021-02-19 modifié : Kicad/Main_board.kicad_pcb modifié : README.md
    [Main_board.kicad_pcb]
2021-02-19 modifié : Kicad/Main_board.kicad_pcb
    [Main_board.kicad_pcb]
